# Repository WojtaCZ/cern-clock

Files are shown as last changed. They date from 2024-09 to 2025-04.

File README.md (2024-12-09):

# CERN CLOCK
This repository contains all the files for the CERN CLOCK project. The [firmware](firmware) folder contains the assembly for the 6809 processor as well as the sources for the RP Pico W. [Hardware](hardware) contains the reverse engineered schematic of the decoder board and the project for the controller board. [Mechanical](mechanical) folder contains the 3D printable parts and outlines for the plexi panels.

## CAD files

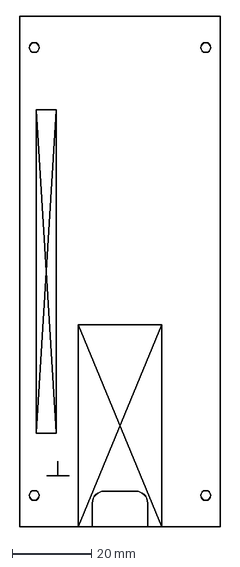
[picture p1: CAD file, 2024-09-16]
hardware/controller/outline.dxf
50.6 x 129.0 mm

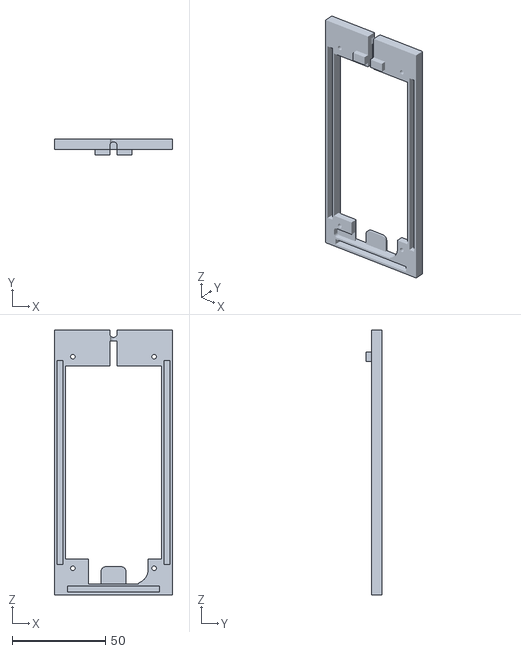
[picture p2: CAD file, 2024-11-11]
mechanical/rear_cover.stl
63.4 x 8.60 x 141.8

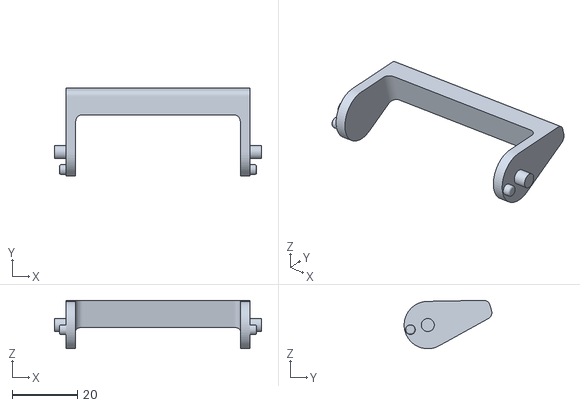
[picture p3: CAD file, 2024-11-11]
mechanical/leg.stl
63.4 x 26.9 x 14.8

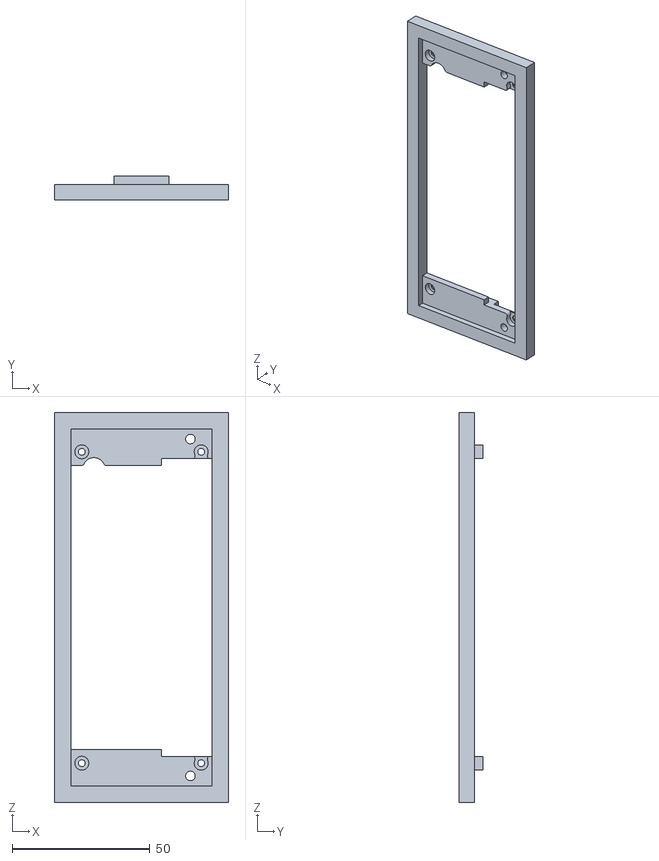
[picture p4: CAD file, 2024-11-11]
mechanical/front_cover.stl
63.4 x 8.60 x 141.8

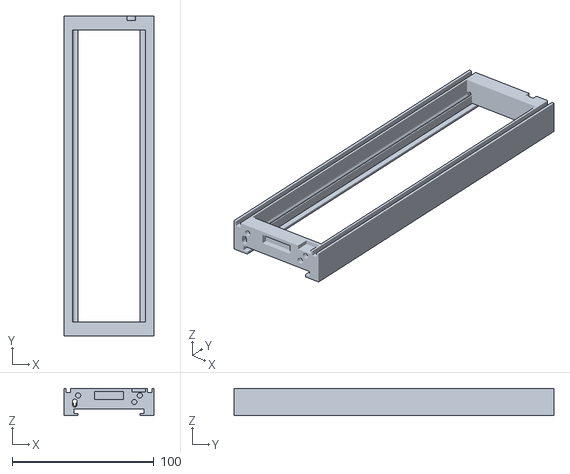
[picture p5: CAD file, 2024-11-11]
mechanical/top_cover.stl
63.4 x 225.5 x 19.3

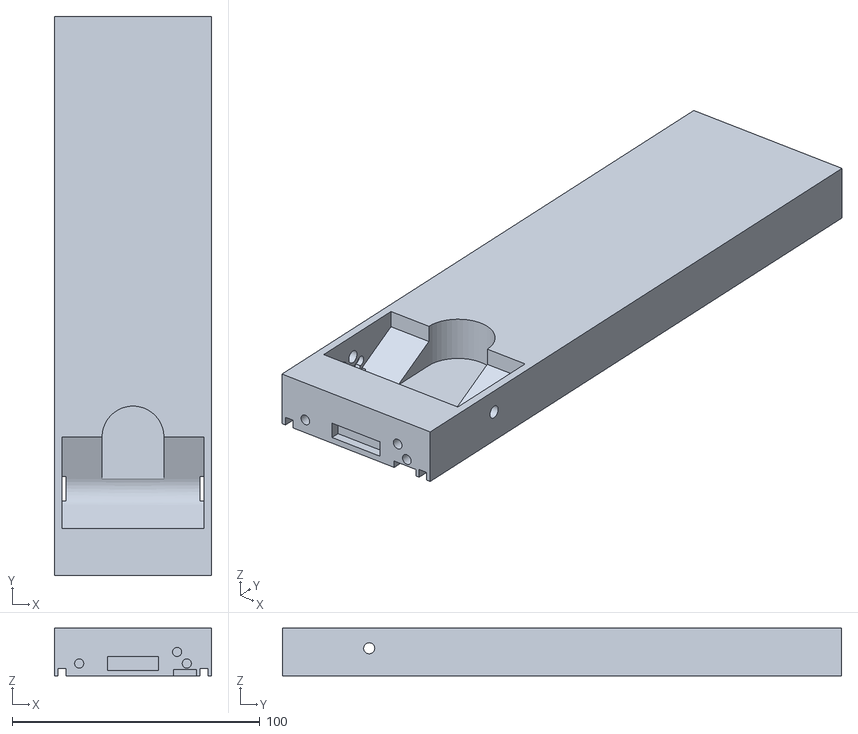
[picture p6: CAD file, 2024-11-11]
mechanical/base.stl
63.4 x 225.5 x 19.3

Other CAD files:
mechanical/cern-clock.f3d

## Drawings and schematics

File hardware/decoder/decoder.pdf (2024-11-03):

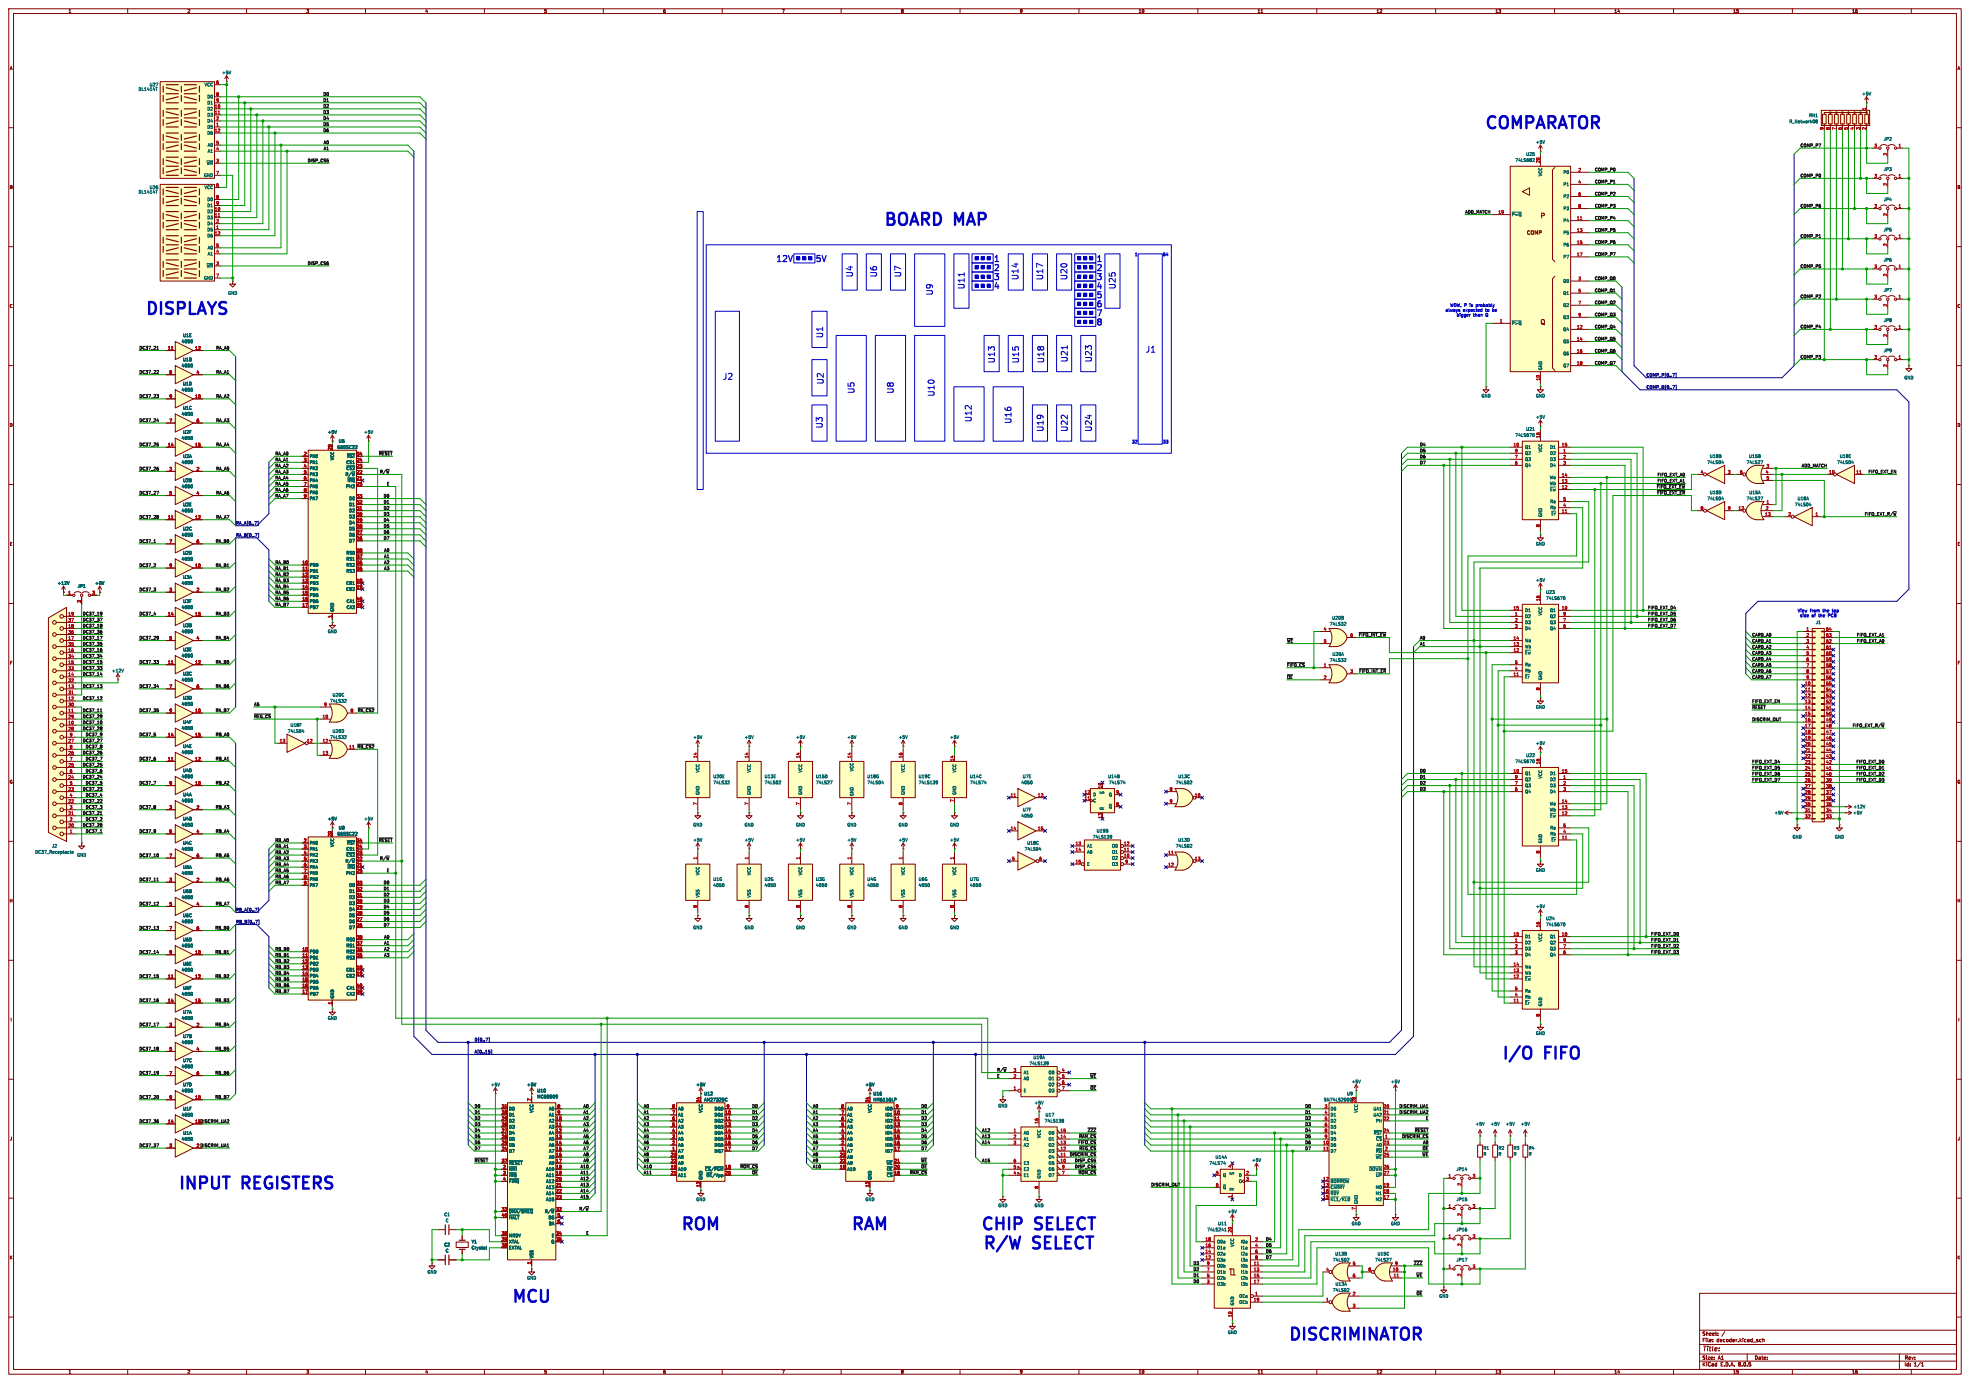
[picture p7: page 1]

WOW, P is probably
always expected to be

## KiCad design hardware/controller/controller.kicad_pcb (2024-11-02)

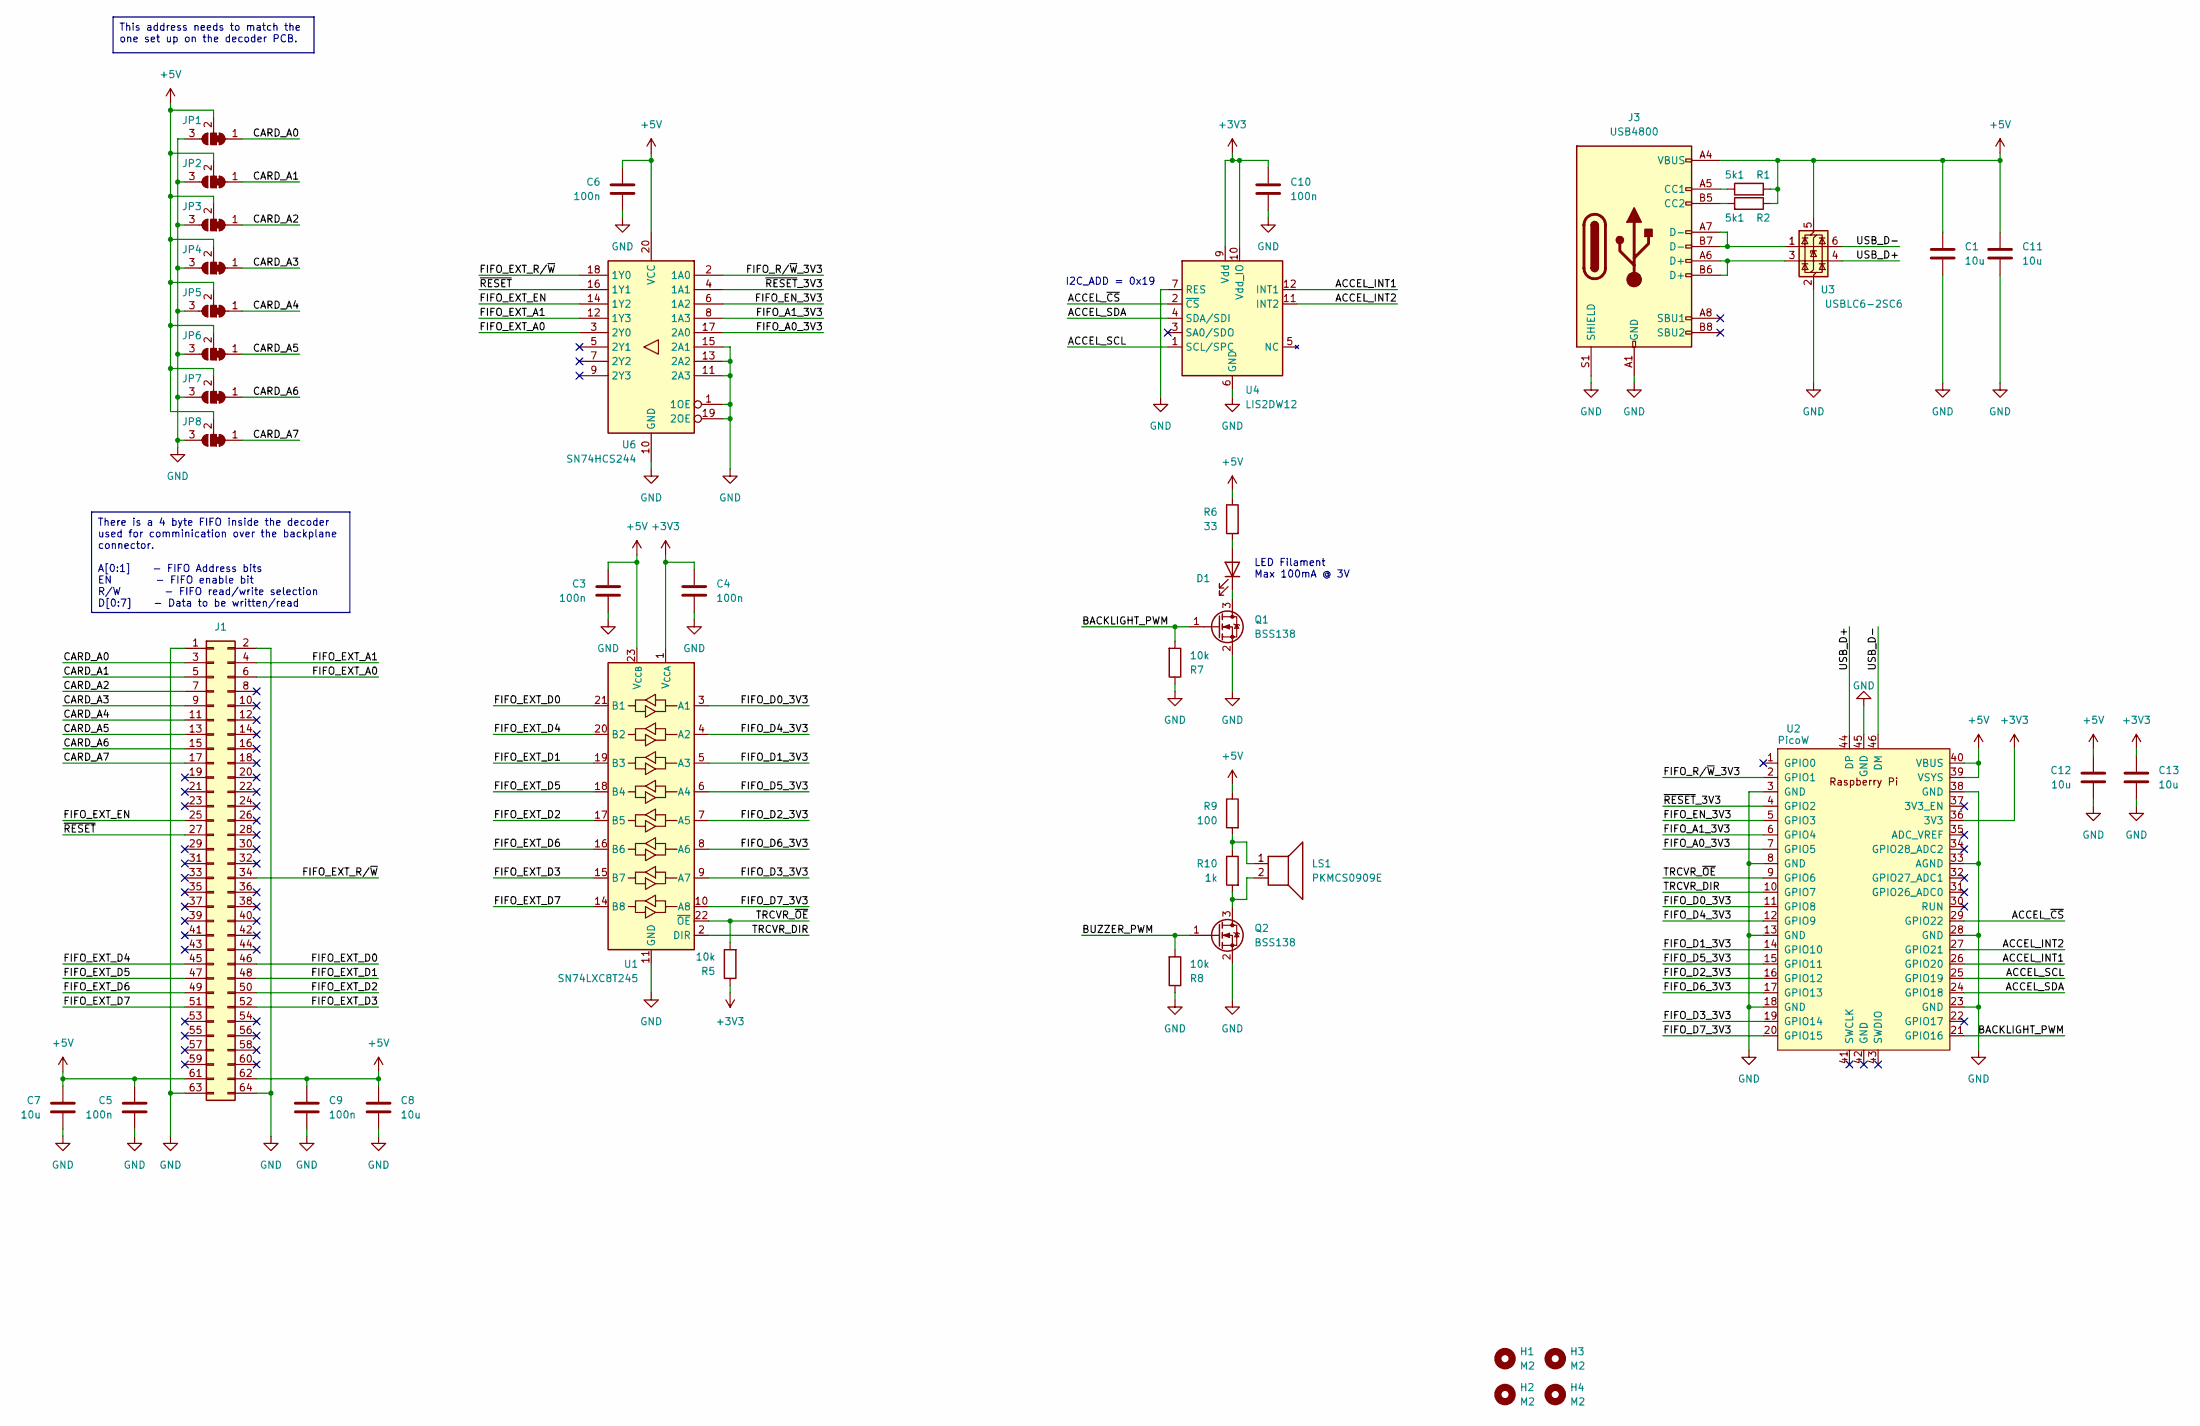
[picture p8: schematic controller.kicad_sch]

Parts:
C1, C7, C8, C11, C12, C13: 10u; C_0603_1608Metric
C3, C4, C5, C6, C9, C10: 100n; C_0603_1608Metric
D1: LED FILAMENT; Con_01x02_2.54_SMD
H1, H2, H3, H4: M2; MountingHole_2.5mm
J1: Conn_02x32_Odd_Even; PinSocket_2x32_P2.54mm_Vertical_SMD
J3: USB4800; USB_C_Receptacle_GCT_USB4800
JP1, JP2, JP3, JP4, JP5, JP6, JP7, JP8: SolderJumper_3_Bridged12; SolderJumper-3_P1.3mm_Bridged2Bar12_Pad1.0x1.5mm
LS1: PKMCS0909E; Buzzer_Murata_PKMCS0909E
Q1, Q2: BSS138; SOT-23
R1, R2: 5k1; R_0603_1608Metric
R5, R7, R8: 10k; R_0603_1608Metric
R6: 33; R_0603_1608Metric
R9: 100; R_0603_1608Metric
R10: 1k; R_0603_1608Metric
U1: SN74LXC8T245; TSSOP-24_4.4x7.8mm_P0.65mm
U2: PicoW; RPi_Pico_SMD_TH
U3: USBLC6-2SC6; SOT-23-6
U4: LIS2DW12; LGA-12_2x2mm_P0.5mm
U6: SN74HCS244; TSSOP-20_4.4x6.5mm_P0.65mm

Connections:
+3V3: C4.1, C10.1, C13.1, R5.1, U1.1 (V_{CCA}), U2.36 (3V3), U4.9 (Vdd), U4.10 (Vdd_IO)
+5V: C1.1, C3.1, C5.1, C6.1, C7.1, C8.1, C9.1, C11.1, C12.1, J1.61, J1.62, J3.A4 (VBUS), J3.A9 (VBUS), J3.B4 (VBUS), J3.B9 (VBUS), JP1.2 (C), JP2.2 (C), JP3.2 (C), JP4.2 (C), JP5.2 (C), JP6.2 (C), JP7.2 (C), JP8.2 (C), R1.2, R2.1, R6.1, R9.1, U1.23 (V_{CCB}), U1.24 (V_{CCB}), U2.39 (VSYS), U2.40 (VBUS), U3.5 (VBUS), U6.20 (VCC)
/ACCEL_INT1: U2.26 (GPIO20), U4.12 (INT1)
/ACCEL_INT2: U2.27 (GPIO21), U4.11 (INT2)
/ACCEL_SCL: U2.25 (GPIO19), U4.1 (SCL/SPC)
/ACCEL_SDA: U2.24 (GPIO18), U4.4 (SDA/SDI)
/ACCEL_~CS: U2.29 (GPIO22), U4.2 (~CS)
/BACKLIGHT_PWM: Q1.1 (G), R7.2, U2.21 (GPIO16)
/BUZZER_PWM: Q2.1 (G), R8.2
/CARD_A0: J1.3, JP1.1 (A)
/CARD_A1: J1.5, JP2.1 (A)
/CARD_A2: J1.7, JP3.1 (A)
/CARD_A3: J1.9, JP4.1 (A)
/CARD_A4: J1.11, JP5.1 (A)
/CARD_A5: J1.13, JP6.1 (A)
/CARD_A6: J1.15, JP7.1 (A)
/CARD_A7: J1.17, JP8.1 (A)
/FIFO_A0_3V3: U2.7 (GPIO5), U6.17 (2A0)
/FIFO_A1_3V3: U2.6 (GPIO4), U6.8 (1A3)
/FIFO_D0_3V3: U1.3 (A1), U2.11 (GPIO8)
/FIFO_D1_3V3: U1.5 (A3), U2.14 (GPIO10)
/FIFO_D2_3V3: U1.7 (A5), U2.16 (GPIO12)
/FIFO_D3_3V3: U1.9 (A7), U2.19 (GPIO14)
/FIFO_D4_3V3: U1.4 (A2), U2.12 (GPIO9)
/FIFO_D5_3V3: U1.6 (A4), U2.15 (GPIO11)
/FIFO_D6_3V3: U1.8 (A6), U2.17 (GPIO13)
/FIFO_D7_3V3: U1.10 (A8), U2.20 (GPIO15)
/FIFO_EN_3V3: U2.2 (GPIO1), U6.2 (1A0)
/FIFO_EXT_A0: J1.6, U6.3 (2Y0)
/FIFO_EXT_A1: J1.4, U6.12 (1Y3)
/FIFO_EXT_D0: J1.46, U1.21 (B1)
/FIFO_EXT_D1: J1.48, U1.19 (B3)
/FIFO_EXT_D2: J1.50, U1.17 (B5)
/FIFO_EXT_D3: J1.52, U1.15 (B7)
/FIFO_EXT_D4: J1.45, U1.20 (B2)
/FIFO_EXT_D5: J1.47, U1.18 (B4)
/FIFO_EXT_D6: J1.49, U1.16 (B6)
/FIFO_EXT_D7: J1.51, U1.14 (B8)
/FIFO_EXT_EN: J1.25, U6.14 (1Y2)
/FIFO_EXT_R/~W: J1.34, U6.18 (1Y0)
/FIFO_R/~W_3V3: U2.4 (GPIO2), U6.4 (1A1)
/TRCVR_DIR: U1.2 (DIR), U2.10 (GPIO7)
/TRCVR_~OE: R5.2, U1.22 (~OE), U2.9 (GPIO6)
/USB_D+: U2.44 (DP), U3.4 (I/O2)
/USB_D-: U2.46 (DM), U3.6 (I/O1)
/~RESET: J1.27, U6.16 (1Y1)
/~RESET_3V3: U2.5 (GPIO3), U6.6 (1A2)
GND: C1.2, C3.2, C4.2, C5.2, C6.2, C7.2, C8.2, C9.2, C10.2, C11.2, C12.2, C13.2, J1.1, J1.2, J1.63, J1.64, J3.A1 (GND), J3.A12 (GND), J3.B1 (GND), J3.B12 (GND), J3.S1 (SHIELD), JP1.3 (B), JP2.3 (B), JP3.3 (B), JP4.3 (B), JP5.3 (B), JP6.3 (B), JP7.3 (B), JP8.3 (B), Q1.2 (S), Q2.2 (S), R7.1, R8.1, U1.11 (GND), U1.12 (GND), U1.13 (GND), U2.3 (GND), U2.8 (GND), U2.13 (GND), U2.18 (GND), U2.23 (GND), U2.28 (GND), U2.33 (AGND), U2.38 (GND), U2.45 (GND), U3.2 (GND), U4.6 (GND), U4.7 (RES), U4.8 (GND), U6.1 (1OE), U6.10 (GND), U6.11 (2A3), U6.13 (2A2), U6.15 (2A1), U6.19 (2OE)
unnamed: D1.2 (A), R6.2
unnamed: D1.1 (K), Q1.3 (D)
unnamed: J3.A5 (CC1), R1.1
unnamed: J3.B5 (CC2), R2.2
unnamed: J3.A6 (D+), J3.B6 (D+), U3.3 (I/O2)
unnamed: J3.A7 (D-), J3.B7 (D-), U3.1 (I/O1)
unnamed: LS1.1, R9.2, R10.1
unnamed: LS1.2, Q2.3 (D), R10.2

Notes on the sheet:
This address needs to match the one set up on the decoder PCB.
There is a 4 byte FIFO inside the decoder used for comminication over the backplane connector. A[0:1] - FIFO Address bits EN - FIFO enable bit R/W - FIFO read/write selection D[0:7] - Data to be written/read
I2C_ADD = 0x19
LED Filament Max 100mA @ 3V

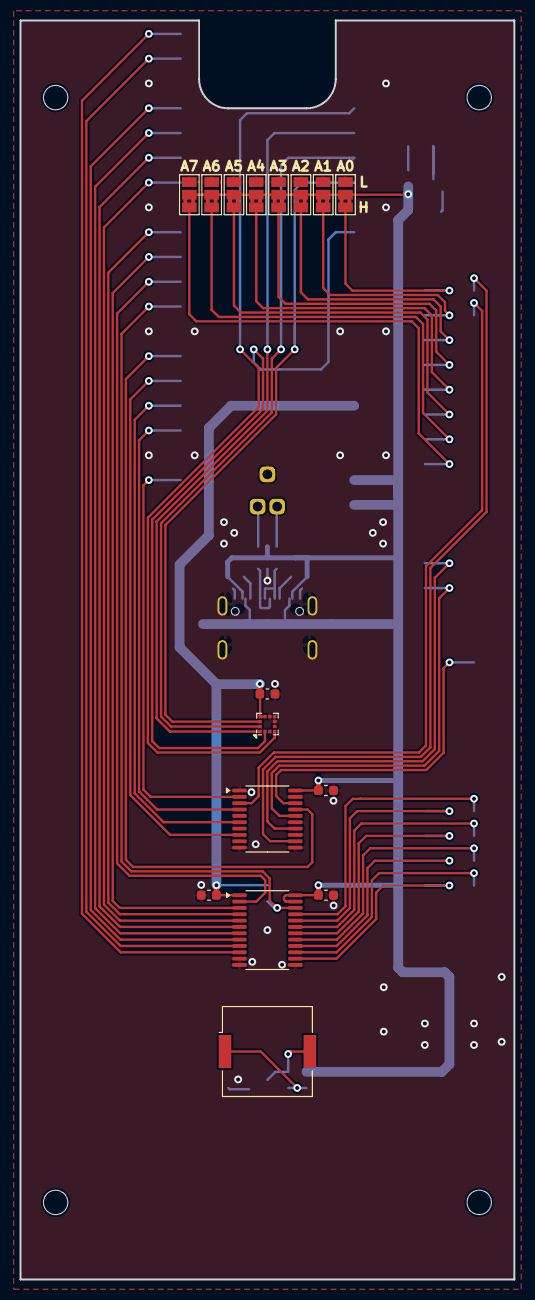
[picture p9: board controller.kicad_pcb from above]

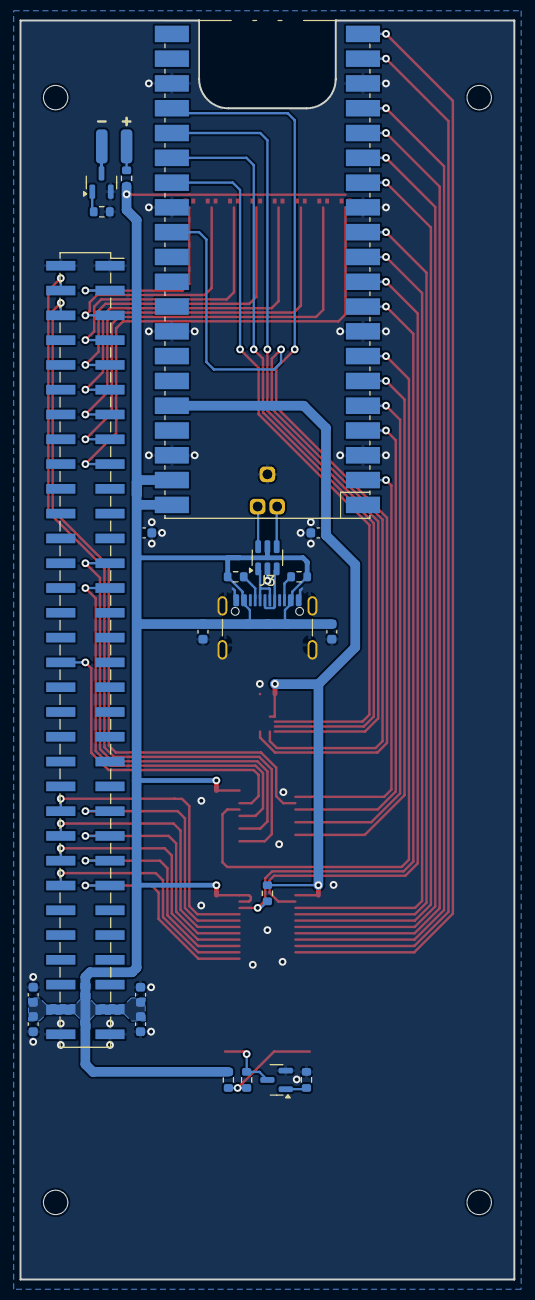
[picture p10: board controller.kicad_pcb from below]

Board: 2 copper layers, 50.6 x 129.0 mm, 43 parts (23 on the bottom side), 56 nets.

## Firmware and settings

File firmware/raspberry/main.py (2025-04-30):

from machine import Pin
from machine import Timer
import decoder
import time
import accelerometer
import ntp
import wireless
import web
import vistars
import asyncio
import backlight
import buzzer
import clock
import logging
logging.basicConfig(level=logging.DEBUG)

# Disable the decoder
decoder.assertReset()

# Variables holding the actve screen ID and indicating screen change
activeScreen = 0
activeScreenOld = -1
activeScreenChanged = True

# Routines to handle returning to home screen after some time
homeTimerLastActivityTimestamp = 0
homeTimerActive = True
HOME_TIMEOUT = 5000

def homeTimerStart():
    global homeTimerLastActivityTimestamp, homeTimerActive, HOME_TIMEOUT

    homeTimerLastActivityTimestamp = time.ticks_ms()
    homeTimerActive = True

def homeTimerStop():
    global homeTimerLastActivityTimestamp, homeTimerActive, HOME_TIMEOUT

    homeTimerActive = False

async def homeTimerProcess():
    global homeTimerLastActivityTimestamp, homeTimerActive, HOME_TIMEOUT
    global activeScreen

    if time.ticks_ms() > (homeTimerLastActivityTimestamp + HOME_TIMEOUT) and homeTimerActive:
        homeTimerStop()
        activeScreen = 0

# Routines to handle periodic NTP syncs
syncHourOld = -1
ntpErrors = 0

async def ntpSyncProcess(timeTuple):
    global syncHourOld, ntpErrors
    
    year, month, mday, hour, minute, second, weekday, yearday = timeTuple
    
    # If the hour has changed from the last one
    if hour != syncHourOld:
        # Try to sync the NTP
        try:
            ntp.sync()
            syncHourOld = hour
            ntpErrors = 0

        # If it failed, increase error counter
        except:
            ntpErrors += 1
                
        # If we were not able to sync for the full day, restart...
        if ntpErrors >= 24:
            clock.restart()


async def displayLoop():
    global activeScreen, activeScreenOld, activeScreenChanged
    global homeTimerLastActivityTimestamp, homeTimerActive, HOME_TIMEOUT

    global syncHourOld
    global ntpErrors
    
    # Set the last activity to be now so the clock doesnt sleep right away
    clock.wakeUp()
    
    while True:
        
        # Get the time
        timeNow = ntp.localTime()

        # Check if the time has passed to go to the home screen
        await homeTimerProcess()

        # See if there is need to sync the NTP
        await ntpSyncProcess(timeNow)

        # Check if the active screen changed or there was a tap
        if activeScreen != activeScreenOld:
            # If so, render the new screen
            activeScreenChanged = True
            activeScreenOld = activeScreen
        
        # If the clock shall not sleep, draw the selected screen
        if not clock.shouldSleep(timeNow):
            # Show the time
            if activeScreen == 0:
                hour = await decoder.zfl(str(timeNow[3]), 2)
                minute = await decoder.zfl(str(timeNow[4]), 2)
                second = await decoder.zfl(str(timeNow[5]), 2)

                await decoder.writeString(hour + ":" + minute + ":" + second)
                
            # Show the date
            elif activeScreen == 1:
                if activeScreenChanged:
                    # Start the home timer
                    homeTimerStart()
                
                day = await decoder.zfl(str(timeNow[2]), 2)
                month = await decoder.zfl(str(timeNow[1]), 2)
                year = str(timeNow[0])[2:4]

                await decoder.writeString(day + "." + month + "." + year)

            # Request the data from the vistars OCR
            elif activeScreen == 2:
                if activeScreenChanged:
                    # Stop the home timer
                    homeTimerStop()
                    
                accelerometer.disable()
                await decoder.writeString("STAV LHC")
                await vistars.getData()

                # After the request finished, show the data
                activeScreen = 3
            # Show the vistars data
            elif activeScreen == 3 and vistars.status != None:
                if activeScreenChanged:
                    homeTimerStart()
                    clock.wakeUp()
                
                # Show the retrieved data
                await decoder.writeString(vistars.status)
                
                accelerometer.enable()

            activeScreenChanged = False

        # If the clock should sleep
        else:
            # Go to home screen and blank the display
            activeScreen = 0
            await decoder.writeString("        ")
            
        # If the accel was tapped
        if accelerometer.tapFlag:  
            # If only once, go to next screen
            if accelerometer.tapCounter == 1:
                activeScreen += 1

            # If more than once, toggle the backlight
            else:
                if await backlight.isLit():
                    await backlight.fadeOff(1000)
                else:
                    await backlight.fadeOn(1000)

            # Clear the flag
            accelerometer.tapFlag = False
                
        # The max number of screens is 4, loop back to 0
        if activeScreen == 4:
            activeScreen = 0
                
        # Sleep for a little
        await asyncio.sleep_ms(50)

# If the wifi doesnt connect, this loop runs forever to notify the user
async def apLoop():
    while True:
        await decoder.writeBanner("PRIPOJ SE K MEMU AP NA ADRESU " + wireless.ADAPTER.ifconfig()[0] + " A NASTAV MI WIFI")


# Load system related config (sleep time)
clock.init()

# Load vistars configuration
vistars.init()

# Enable the decoder
decoder.deassertReset()

# Play the turnon animation
clock.turnOnSequence()

# Init the accelerometer
try:       
    accelerometer.init()

# If it failed, thats fatal...
except:
    buzzer.beepERR()
    while True:
        decoder.writeBannerSync("FATALNI CHYBA! NELZE NASTAVIT AKCELEROMETR")

# If the clock has not been setup yet, run through the first setup
if clock.FIRST_SETUP:
    clock.firstSetupSequence()

# Try to init the wireless 
try:
    wireless.init()

# If it fails, thats fatal... Loop forever
except:
    buzzer.beepERR()
    while True:
        decoder.writeBannerSync("FATALNI CHYBA! NELZE AKTIVOVAT WIFI ANI AP")
        
# If the wireless was initialized but in the AP mode (not able to connect to wifi)
if wireless.apActive:
    # Run the AP loop together with the WEB interface to allow for configuration
    web.app.loop.create_task(apLoop())
    web.app.run(host="0.0.0.0", port=80)

# Sync the NTP
try:
    decoder.writeStringSync("ZISKAVAM")
    time.sleep_ms(1000)
    decoder.writeStringSync(" PRESNE ")
    time.sleep_ms(1000)
    decoder.writeStringSync(" HODINY ")
    time.sleep_ms(1000)
    
    ntp.init()
    ntp.sync()

# If it failed, thats fatal...
except:
    buzzer.beepERR()
    while True:
        decoder.writeBannerSync("FATALNI CHYBA! NELZE SYNCHRONIZOVAT NTP")

accelerometer.enable()

# If all went well, register the display loop as an async task to run alongside the webserver
web.app.loop.create_task(displayLoop()) 
# Run the main app  
web.app.run(host="0.0.0.0", port=80)



        




    

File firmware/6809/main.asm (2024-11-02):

; Base adresses for all peripherals
RESET_VECTOR equ $FFFE
ROM_BASE equ $F000
DISP2_BASE equ $E000
DISP1_BASE equ $D000
DISCRIM_BASE equ $C000
REG_BASE equ $B000
FIFO_BASE equ $A000
RAM_BASE equ $9000
ZZZ_BASE equ $8000

; Place the init function at the base of the ROM memor
    org ROM_BASE
init:
    ; Blank out all the displays
    clra
    lda #32 

    ; Load the DISP1 base into index register X
	ldx #DISP1_BASE

	; Load the test characters into the first display
	sta ,X+
	sta ,X+
	sta ,X+
	sta ,X+

	; Load the DISP2 base into index register X
	ldx #DISP2_BASE

	; Load the test characters into the second display
	sta ,X+
	sta ,X+
	sta ,X+
	sta ,X+

loop:

    ; Write the index of the display to be written to FIFO byte 0
    clra
    lda #1
    ldx #FIFO_BASE
    sta ,X

; Now, wait for it to be zeroed out by the RPI - this serves as a confirmation that the index has been read
    ldx #FIFO_BASE
zerowait_disp1:
    lda ,X
    bne zerowait_disp1

; Wait for the RPI to fill the fifo with data
    ldx #FIFO_BASE
nonzerowait_disp1:
    lda ,X
    beq nonzerowait_disp1

    ; Copy the contents of the FIFO to the first display
    ldx #FIFO_BASE
    ldy #DISP1_BASE

    lda 3,X
    sta 3,Y

    lda 2,X
    sta 2,Y

    lda 1,X
    sta 1,Y

    lda ,X
    sta ,Y

    ; Write the index of the display to be written to FIFO byte 0
    clra
    lda #2
    ldx #FIFO_BASE
    sta ,X

; Now, wait for it to be zeroed out
    ldx #FIFO_BASE
zerowait_disp2:
    lda ,X
    bne zerowait_disp2

; Wait for the RPI to fill the fifo with data
    ldx #FIFO_BASE
nonzerowait_disp2:
    lda ,X
    beq nonzerowait_disp2

    ; Copy the contents of the FIFO to the second display
    ldx #FIFO_BASE
    ldy #DISP2_BASE

    lda 3,X
    sta 3,Y

    lda 2,X
    sta 2,Y

    lda 1,X
    sta 1,Y

    lda ,X
    sta ,Y

    ; Jump back to the beginning
    jmp loop



; Place the init function address at the origin of reset vector
    org RESET_VECTOR
    fdb init

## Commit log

2024-05-26 Finished decoder board schematic
    [decoder.kicad_pcb, decoder.kicad_sch, decoder_baseboard.kicad_pcb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]
2024-09-16 Added PICO footprint and USB
    [USB4800-03-A.stp, decoder_baseboard.kicad_pcb, decoder_baseboard.kicad_sch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]
2024-09-17 Some routing done
    [decoder_baseboard.kicad_pcb, decoder_baseboard.kicad_sch]
2024-09-18 routing done
    [decoder.kicad_sch, decoder_baseboard.kicad_pcb]
2024-10-01 finished rounded version
    [decoder_baseboard-rounded.kicad_pcb]
2024-11-02 Got FW working
    [decoder_baseboard.kicad_pcb, decoder_baseboard.kicad_sch]
2024-11-03 Fixed some issues with the FW
    [main.py]
2024-11-11 Added mechanical parts
    [base.stl, cern-clock.f3d, front_cover.stl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]
2024-11-14 Sockets not working for some reason
    [main.py, ntp.py, vistars.py]
2024-12-09 Added gitignore
    [controller-rounded.kicad_pcb, controller.kicad_pcb, controller.kicad_sch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]
2024-12-14 Added sample configuration
2025-04-30 Wakeup timer restart when vistars shows data
2025-04-30 Fixed tap timer
